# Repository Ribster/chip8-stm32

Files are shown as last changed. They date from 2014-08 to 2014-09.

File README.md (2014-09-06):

CHIP 8 emulator
==========

STM32 based emulator with chip8 virtual machine.

Dirs
==========
tools/	dir with conwerter of image in propertly format
mcu/	program writen to mcu (Eclipse progect)
pcb/	schematics and pcb ready to laser printer production (Eagle)

How to repeat
==========

1. Product pcb
2. SMT components
3. Compile or use prebuild hex/elf files to write in mcu
4. Enjoy

TODO
==========
1. Transfer to new random generator
2. Add button patterns to game (now button worked propertly only in tetris)
3. Add to disign Beeper 
4. Redisign schematics
5. Create case for console

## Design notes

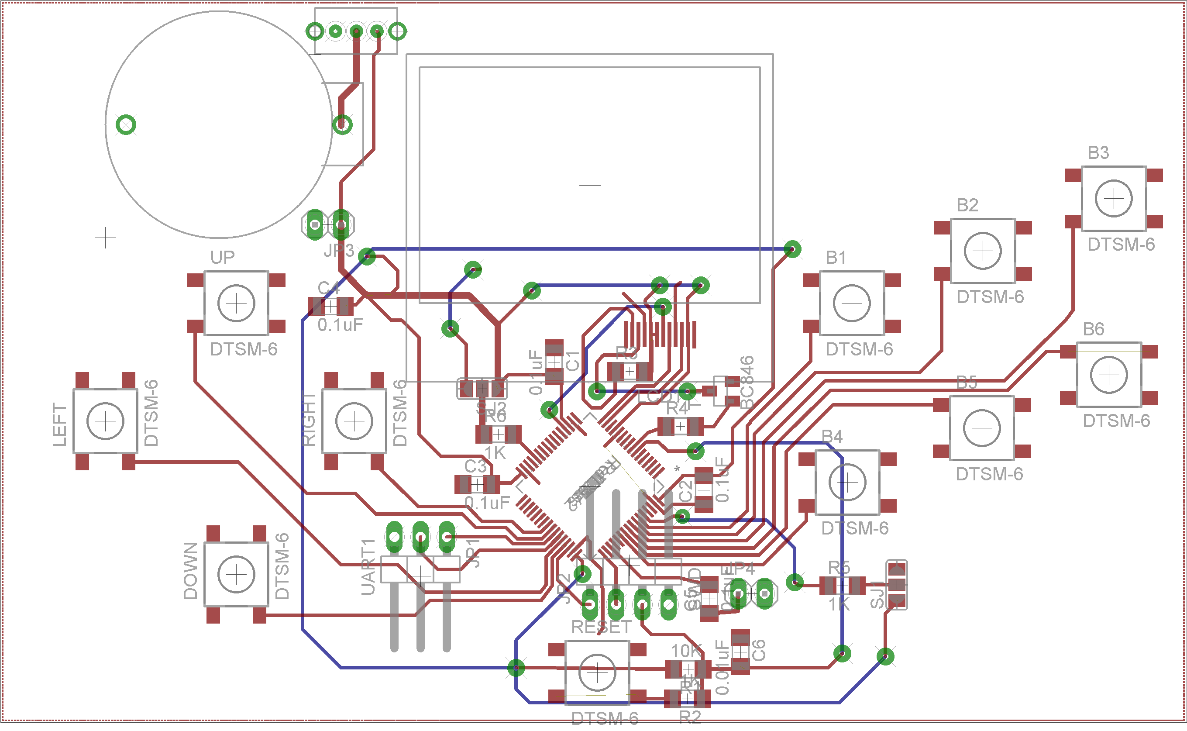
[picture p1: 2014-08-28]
pcb/render/main_board_pcb_elements+2layer.png

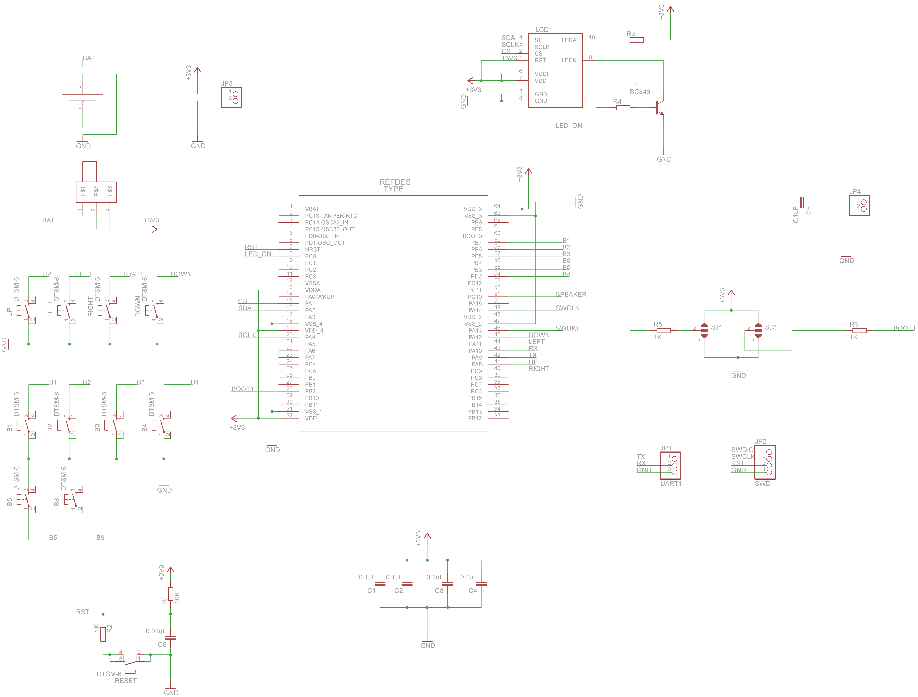
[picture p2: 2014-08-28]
pcb/render/main_board.png

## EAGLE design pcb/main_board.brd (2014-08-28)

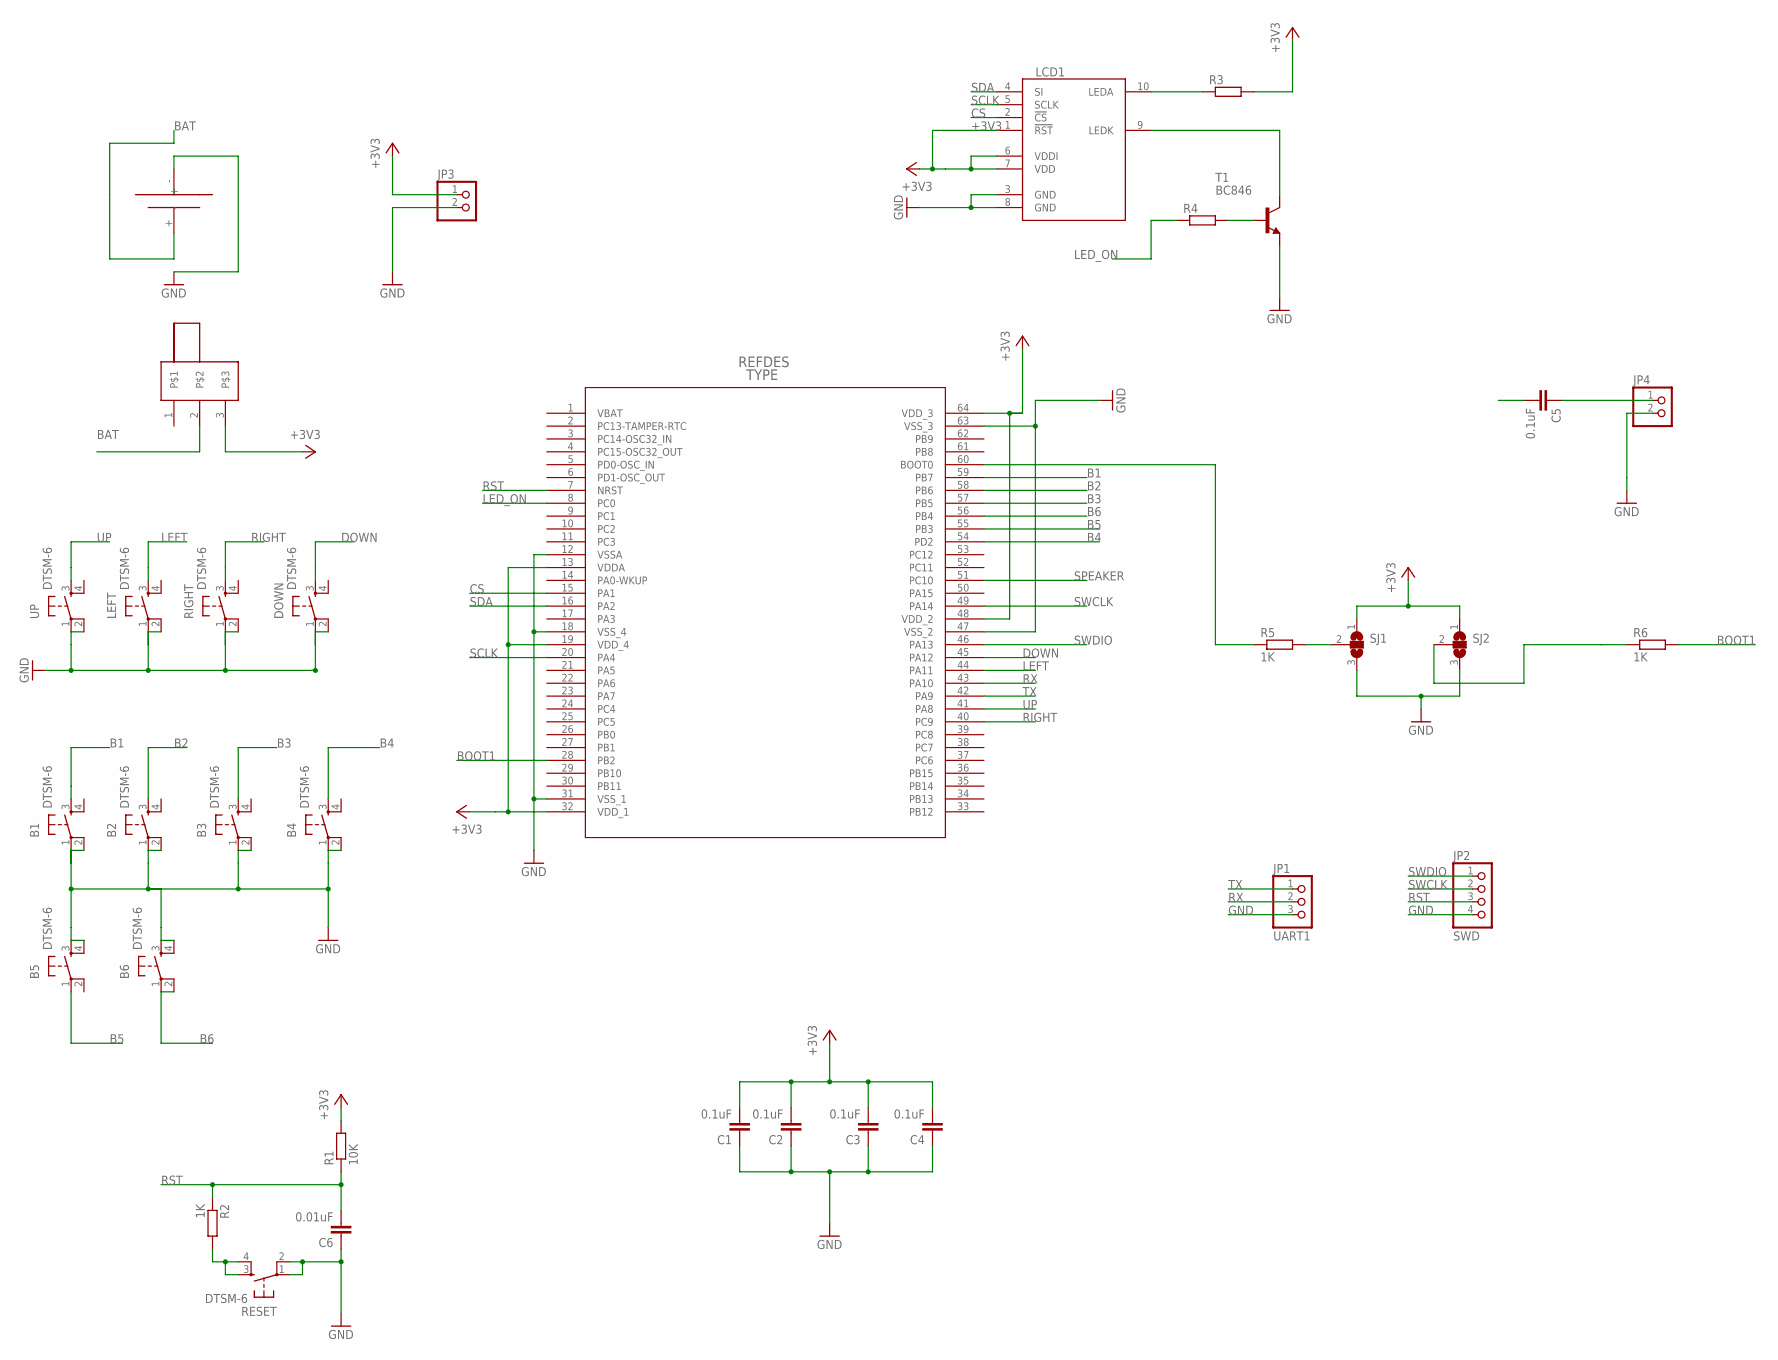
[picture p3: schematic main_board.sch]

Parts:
B1, B2, B3, B4, B5, B6: DTSM-6
C1, C2, C3, C4, C5: 0.1uF; C1206
C6: 0.01uF; C1206
DOWN: DTSM-6
JP1: UART1; 1X03/90
JP2: SWD; 1X04/90
JP3, JP4: PINHD-1X2; 1X02
LCD1: LCD1202; NOKIA1202LCD
LEFT: DTSM-6
R1: 10K; R1206
R2, R5, R6: 1K; R1206
R3, R4: R-EU_R1206; R1206
RESET: DTSM-6
RIGHT: DTSM-6
SJ1, SJ2: SJ2W; SJ_2
T1: BC846; SOT23
U$1: STM32F100RBT6B; LQFP-64
U$2: BAT33; 3V3BATPACK
U$3: SWITCH3
UP: DTSM-6

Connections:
+3V3: C1.2, C2.2, C3.2, C4.2, JP3.1, LCD1.1 (!RST), LCD1.6 (VDDI), LCD1.7 (VDD), R1.2, R3.2, SJ1.1, SJ2.1, U$1.13 (VDDA), U$1.19 (VDD_4), U$1.32 (VDD_1), U$1.48 (VDD_2), U$1.64 (VDD_3), U$3.3
B1: B1.3, U$1.59 (PB7)
B2: B2.3, U$1.58 (PB6)
B3: B3.3, U$1.57 (PB5)
B4: B4.3, U$1.54 (PD2)
B5: B5.1, U$1.55 (PB3)
B6: B6.1, B6.2, U$1.56 (PB4)
BAT: U$2.+, U$3.2
BOOT1: R6.2, U$1.28 (PB2)
CS: LCD1.2 (!CS), U$1.15 (PA1)
DOWN: DOWN.3, U$1.45 (PA12)
GND: B1.1, B1.2, B2.1, B2.2, B3.1, B3.2, B4.1, B4.2, B5.3, B5.4, B6.3, B6.4, C1.1, C2.1, C3.1, C4.1, C6.1, DOWN.1, DOWN.2, JP1.3, JP2.4, JP3.2, JP4.2, LCD1.3 (GND), LCD1.8 (GND), LEFT.1, LEFT.2, RESET.1, RESET.2, RIGHT.1, RIGHT.2, SJ1.3, SJ2.3, T1.2 (E), U$1.12 (VSSA), U$1.18 (VSS_4), U$1.31 (VSS_1), U$1.47 (VSS_2), U$1.63 (VSS_3), U$2.-, UP.1, UP.2
LED_ON: R4.1, U$1.8 (PC0)
LEFT: LEFT.3, U$1.44 (PA11)
unnamed: LCD1.9 (LEDK), T1.3 (C)
unnamed: R4.2, T1.1 (B)
unnamed: R2.2, RESET.3, RESET.4
unnamed: LCD1.10 (LEDA), R3.1
unnamed: R5.1, U$1.60 (BOOT0)
unnamed: R5.2, SJ1.2
unnamed: C5.1, JP4.1
unnamed: R6.1, SJ2.2
RIGHT: RIGHT.3, U$1.40 (PC9)
RST: C6.2, JP2.3, R1.1, R2.1, U$1.7 (NRST)
RX: JP1.2, U$1.43 (PA10)
SCLK: LCD1.5 (SCLK), U$1.20 (PA4)
SDA: LCD1.4 (SI), U$1.16 (PA2)
SPEAKER: C5.2, U$1.51 (PC10)
SWCLK: JP2.2, U$1.49 (PA14)
SWDIO: JP2.1, U$1.46 (PA13)
TX: JP1.1, U$1.42 (PA9)
UP: U$1.41 (PA8), UP.3

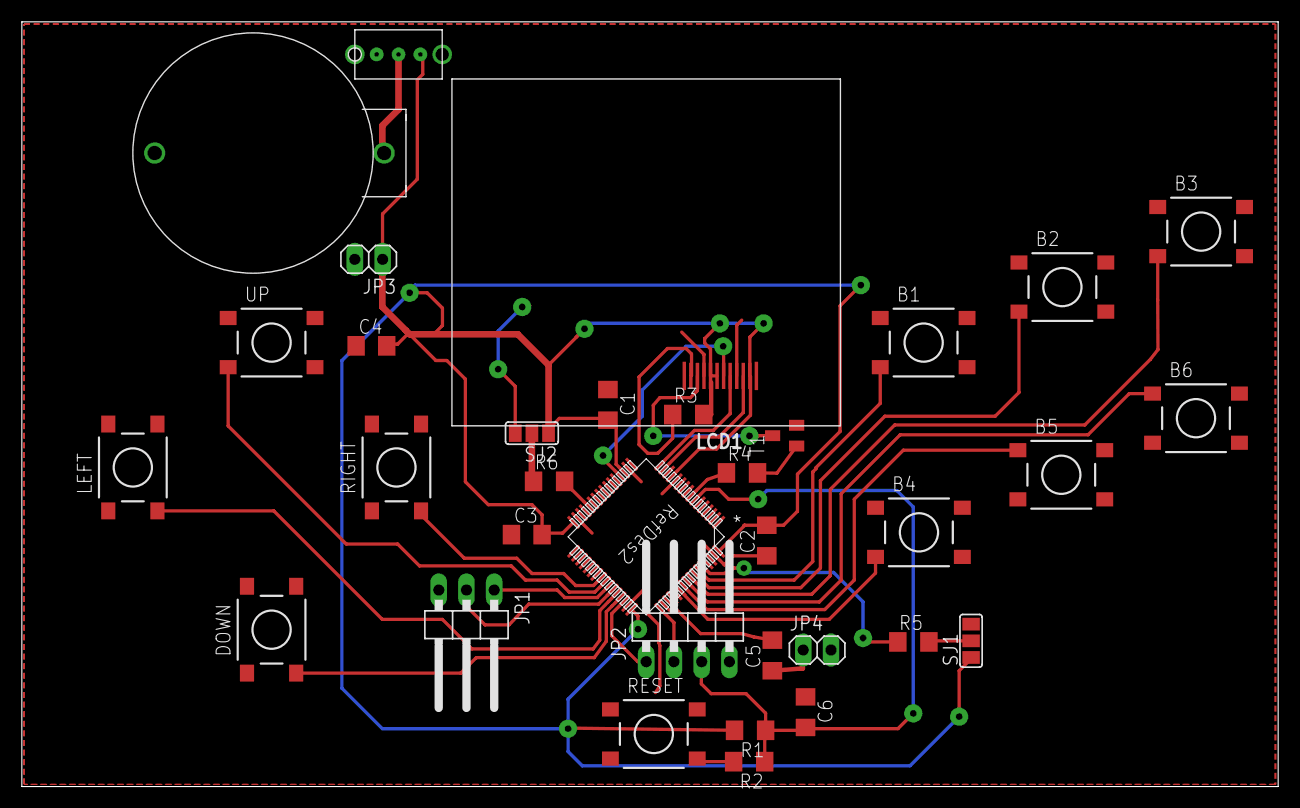
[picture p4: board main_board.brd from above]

Board: 2 copper layers, 115.0 x 70.0 mm, 34 parts (0 on the bottom side), 32 nets.

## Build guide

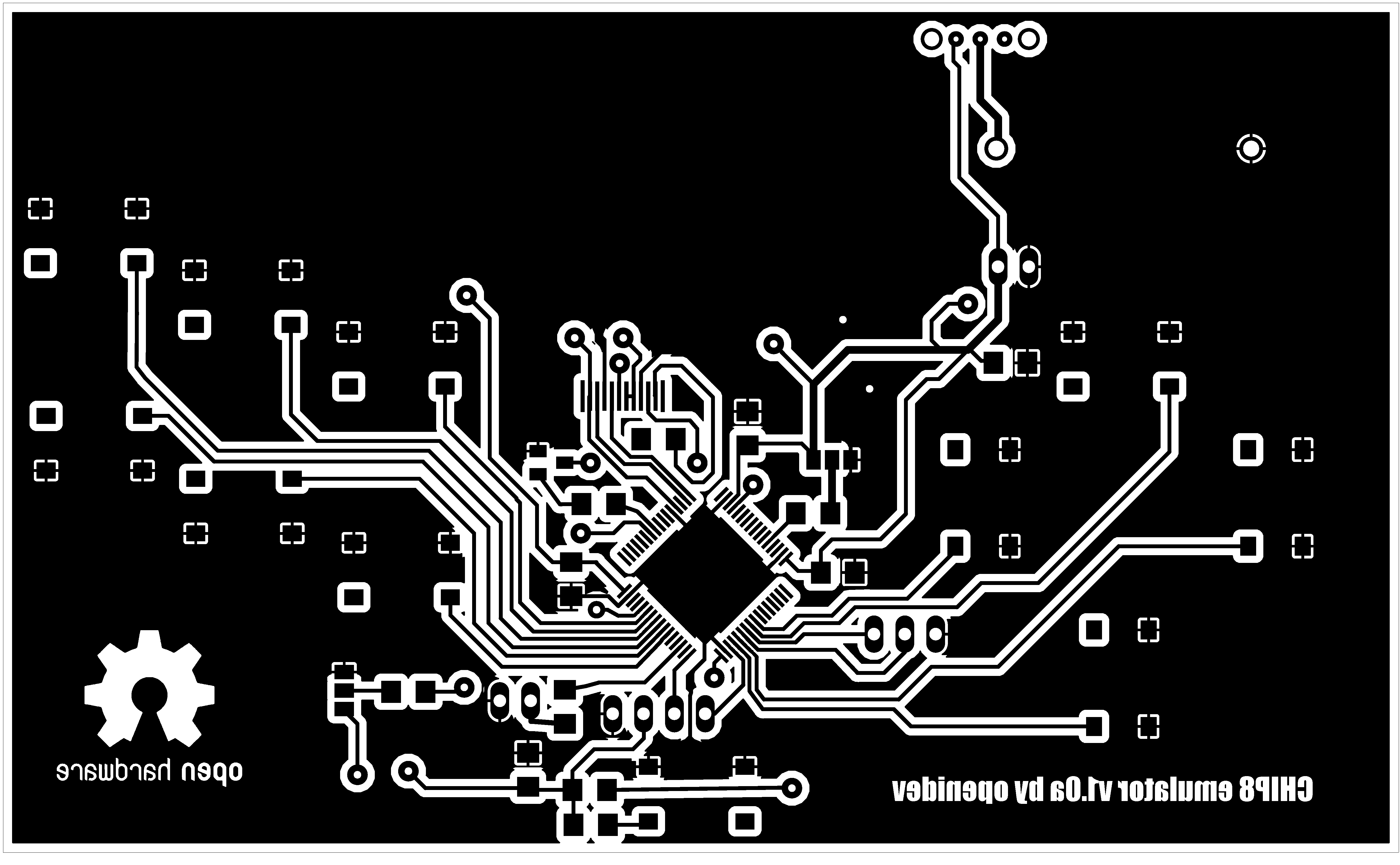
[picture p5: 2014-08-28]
pcb/render/main_board_Laser_Printer_ready_mirored.png

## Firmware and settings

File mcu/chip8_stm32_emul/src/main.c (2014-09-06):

/*
 * main.c
 *
 *  Created on: 25.08.2014
 *      Author: sasha
 */

#include "main.h"

GPIO_InitTypeDef GPIO_InitStructure;
USART_InitTypeDef USART_InitStructure;
USART_ClockInitTypeDef USART_ClockInitStruct;
EXTI_InitTypeDef EXTI_InitStructure;
NVIC_InitTypeDef NVIC_InitStructure;

volatile uint32_t timer;
volatile unsigned int SysTickDelay;

char test[] = "test";
char *disp_string;
char update_lcd;


//Main menu
char select_b;
uint8_t press, current, quit;
volatile uint8_t btn_old_state[10];
volatile uint8_t btn_state[10];


void EnableExti(uint32_t line)
{
	EXTI_InitStructure.EXTI_Line = line;
	EXTI_InitStructure.EXTI_Mode = EXTI_Mode_Interrupt;
	EXTI_InitStructure.EXTI_Trigger = EXTI_Trigger_Falling;
	EXTI_InitStructure.EXTI_LineCmd = ENABLE;
	EXTI_Init(&EXTI_InitStructure);


	/*NVIC_InitStructure.NVIC_IRQChannel = irq;
	NVIC_InitStructure.NVIC_IRQChannelPreemptionPriority = 0x01;
	NVIC_InitStructure.NVIC_IRQChannelSubPriority = 0x01;
	NVIC_InitStructure.NVIC_IRQChannelCmd = ENABLE;
	NVIC_Init(&NVIC_InitStructure);*/

}

void initButtons(void)
{
	GPIO_PinRemapConfig(GPIO_Remap_SWJ_NoJTRST, ENABLE);
	GPIO_PinRemapConfig(GPIO_Remap_SWJ_JTAGDisable, ENABLE);


	GPIO_InitStructure.GPIO_Mode = GPIO_Mode_IPU;
	GPIO_InitStructure.GPIO_Pin = GPIO_Pin_3 | GPIO_Pin_4 | GPIO_Pin_5 | GPIO_Pin_6 | GPIO_Pin_7;
	GPIO_InitStructure.GPIO_Speed = GPIO_Speed_2MHz;
	GPIO_Init(GPIOB, &GPIO_InitStructure);

	GPIO_InitStructure.GPIO_Pin = GPIO_Pin_2;
	GPIO_Init(GPIOD, &GPIO_InitStructure);

	GPIO_InitStructure.GPIO_Pin = GPIO_Pin_8 | GPIO_Pin_11 | GPIO_Pin_12;
	GPIO_Init(GPIOA, &GPIO_InitStructure);

	GPIO_InitStructure.GPIO_Pin = GPIO_Pin_9;
	GPIO_Init(GPIOC, &GPIO_InitStructure);

	//Button b1,b2,b3,b5,b6
	GPIO_EXTILineConfig(GPIO_PortSourceGPIOB, GPIO_PinSource3);
	GPIO_EXTILineConfig(GPIO_PortSourceGPIOB, GPIO_PinSource4);
	GPIO_EXTILineConfig(GPIO_PortSourceGPIOB, GPIO_PinSource5);
	GPIO_EXTILineConfig(GPIO_PortSourceGPIOB, GPIO_PinSource6);
	GPIO_EXTILineConfig(GPIO_PortSourceGPIOB, GPIO_PinSource7);
	//Button b4
	GPIO_EXTILineConfig(GPIO_PortSourceGPIOD, GPIO_PinSource2);

	//Button down, left, up
	GPIO_EXTILineConfig(GPIO_PortSourceGPIOA, GPIO_PinSource8);
	GPIO_EXTILineConfig(GPIO_PortSourceGPIOA, GPIO_PinSource11);
	GPIO_EXTILineConfig(GPIO_PortSourceGPIOA, GPIO_PinSource12);
	//button right
	GPIO_EXTILineConfig(GPIO_PortSourceGPIOC, GPIO_PinSource9);

	EnableExti(EXTI_Line2);
	EnableExti(EXTI_Line3);
	EnableExti(EXTI_Line4);
	EnableExti(EXTI_Line5);
	EnableExti(EXTI_Line6);
	EnableExti(EXTI_Line7);
	EnableExti(EXTI_Line8);
	EnableExti(EXTI_Line9);
	EnableExti(EXTI_Line11);
	EnableExti(EXTI_Line12);

	NVIC_EnableIRQ(EXTI2_IRQn);
	NVIC_EnableIRQ(EXTI3_IRQn);
	NVIC_EnableIRQ(EXTI4_IRQn);
	NVIC_EnableIRQ(EXTI9_5_IRQn);
	NVIC_EnableIRQ(EXTI15_10_IRQn);

	//EnableIRQ(EXTI2_IRQn, EXTI_Line2);
}

void main(void)
{
	  SysTick_Config(SystemCoreClock /1000);

	  /* Включаем тактирование порта C */
	  RCC_APB2PeriphClockCmd(RCC_APB2Periph_GPIOA | RCC_APB2Periph_GPIOC |
			  	  	  	  	 RCC_APB2Periph_GPIOB | RCC_APB2Periph_GPIOB |
			  	  	  	  	 RCC_APB2Periph_GPIOD | RCC_APB2Periph_AFIO, ENABLE);

	  RCC_APB1PeriphClockCmd(RCC_APB1Periph_USART2 , ENABLE);


	  initButtons();


	  /* Init usart spi */
	  GPIO_InitStructure.GPIO_Pin = GPIO_Pin_2 | GPIO_Pin_4;
	  GPIO_InitStructure.GPIO_Mode = GPIO_Mode_Out_PP;
	  GPIO_InitStructure.GPIO_Speed = GPIO_Speed_10MHz;

	  GPIO_Init( GPIOA , &GPIO_InitStructure);

	  /*USART_Cmd(USART2, ENABLE);
	  USART_InitStructure.USART_BaudRate = 9600;
	  USART_InitStructure.USART_WordLength = USART_WordLength_9b;
	  USART_InitStructure.USART_StopBits = USART_StopBits_1;
	  USART_InitStructure.USART_Parity = USART_Parity_No ;
	  USART_InitStructure.USART_Mode = USART_Mode_Tx;
	  USART_InitStructure.USART_HardwareFlowControl = USART_HardwareFlowControl_None;*/
	  /* Configure USART2 */
	  //USART_Init(USART2, &USART_InitStructure);

	  //USART1->BRR = 0x0010;

	  /* Configure USART2 clock*/
	  /*USART_ClockStructInit(&USART_ClockInitStruct);
	  USART_ClockInitStruct.USART_Clock = USART_Clock_Enable;
	  USART_ClockInitStruct.USART_LastBit = USART_LastBit_Enable;
	  USART_ClockInit(USART2, &USART_ClockInitStruct);*/


	  /* Init lcd led control pin */
	  GPIO_InitStructure.GPIO_Mode = GPIO_Mode_Out_PP;
	  GPIO_InitStructure.GPIO_Pin = GPIO_Pin_0;
	  GPIO_InitStructure.GPIO_Speed = GPIO_Speed_2MHz;
	  GPIO_Init(GPIOC, &GPIO_InitStructure);


	  /* Init lcd controll CS signal */
	  GPIO_InitStructure.GPIO_Mode = GPIO_Mode_Out_PP;
	  GPIO_InitStructure.GPIO_Pin = GPIO_Pin_1;
	  GPIO_InitStructure.GPIO_Speed = GPIO_Speed_2MHz;
	  GPIO_Init(GPIOA, &GPIO_InitStructure);


	  /* ON LED backlight */
	  GPIO_SetBits(GPIOC, GPIO_Pin_0);


	  uint8_t i;
	  for (i=0;i<10;i++) {
			btn_old_state[i] = btn_state[i] = 0;
	  }

	  press=1;
	  quit=0;
	  current=1;
	  select_b=0;


	  disp_string = test;
	  update_lcd = 1;

	  /*-----------------*/
	  	lcd_init();
	  	//lcd_segment_direction(1);
	  	lcd_column_direction(1);
	  	//lcd_flags.inverse_char = -1;
	  	lcd_image(0, 0, 8, 96, CHIP8);
	  	delay_ms(1000);
	  	//do __NOP(); while (1); // зависаем
	  	lcd_clr();
	    lcd_str_center(lcdRows()-1, "chip8 emulator");

	    //int cnt = 0;
	    //int i = 0;
	    //uint8_t okeys = 0xFF;

	for(;;) {
	    while(1)
	    {
	        //int n = cnt;
	        //uint8_t keys = (~GPIOB->IDR) & 0x1F;
	        //uint8_t keys = GPIOB->IDR & 0b11111111;


			if(!press) break;

			if(current!=select_b){
				lcd_clr();
				lcd_image(lcdRows()/2, lcdWidth()-15, 1, 4, menu_cursor);
				if(select_b!=0) {
					lcd_str(lcdRows()/2-1, 20, menu_table[select_b-1]);
				}
				lcd_str(lcdRows()/2, 20, menu_table[select_b]);
				if(select_b<MENU_LEN) {
					lcd_str(lcdRows()/2+1, 20, menu_table[select_b+1]);
				}

				current=select_b;

				//lcd_str(0, 0, disp_string);
			}

	    	if(update_lcd)
	    	{
	        //lcd_str(0, 0, disp_string);
	        update_lcd = 0;
	    	}

	    	//delay_ms(100);
			update_controll_button();

	  	    //disp_string = test;
	  	    //update_lcd = 1;

	        /*for(i=6; i>=0; i--)
	        {
	            //ledOn();
	            lcd_big_char(1, 2+i*13, (n % 10)+'0');
	            //ledOff();
	            n /= 10;

	            if(keys != okeys)
	            {
	                if(keys & (1<<i))
	                    lcd_big_char(4, 2+i*13, i+'0');
	                else
	                    lcd_big_char(4, 2+i*13, '0'+14);
	            }
	        }*/
	        //okeys = keys;
	        // lcd_start_line(cnt>>8);

	        //cnt++;
	        //if(cnt>9999999) cnt = 0;
	    }

		init8();
		loadApplication(prog_table[current],prog_size[current]);
		//loadApplication(MAZE,38);
		uint8_t x,y;
		while(1) {
			emulateCycle();
			delay_ms(5);
			if(drawFlag) {
				//lcd_clr();
				for(y = 18; y < 50; ++y)
				{
					for(x = 20; x < 84; ++x)
					{
						if(gfx[((y-18)*64) + (x-20)] == 0)
							lcd_pixel(100-x,y,PIXEL_OFF);
						else
							lcd_pixel(100-x,y,PIXEL_ON);
					}
				}
				/*for(y = 0; y < 32; y++)
				{
					for(x = 0; x < 64; x++)
					{
						if(gfx[(y*64) + x] == 0)
							lcd_pixel(x,y,PIXEL_OFF);
						else
							lcd_pixel(x,y,PIXEL_ON);
					}
				}*/
				drawFlag = false;
				lcd_update();
				//lcd_str(0, 0, disp_string);
			}
			update_game_button();

			if(quit)
			{
				press=1;
				quit = 0;
				current=1;
				select_b=0;
				break;
			}

		}

	}
/*-----------------*/
	  do __NOP(); while (1); // зависаем
}


void update_controll_button()
{
	if (btn_state[UP] && GPIO_ReadInputDataBit(GPIOA, GPIO_Pin_8))
	{
		select_b--;
		//delay_ms(200);
		btn_state[UP] = 0;
	}
	if (btn_state[DOWN] && GPIO_ReadInputDataBit(GPIOA, GPIO_Pin_12))
	{
		select_b++;
		//delay_ms(200);
		btn_state[DOWN] = 0;
	}
	if (btn_state[B4]&& GPIO_ReadInputDataBit(GPIOD, GPIO_Pin_2))
	{
		press=0;
		//delay_ms(200);
		btn_state[B4] = 0;
	}

	if (btn_state[B5]&& GPIO_ReadInputDataBit(GPIOB, GPIO_Pin_3))
	{
		if(GPIO_ReadInputDataBit(GPIOC, GPIO_Pin_0))
			GPIO_ResetBits(GPIOC, GPIO_Pin_0);
		else
			GPIO_SetBits(GPIOC, GPIO_Pin_0);
		//delay_ms(200);
		btn_state[B5] = 0;
	}
	//egg
	if (btn_state[B6]&& GPIO_ReadInputDataBit(GPIOB, GPIO_Pin_4))
	{
		lcd_image(0, 0, 8, 96, BAW);
		btn_state[B6] = 0;
	}

	if(select_b == 255) select_b=MENU_LEN;
	if(select_b > MENU_LEN) select_b=0;

}

void update_game_button() {
	byte i[5];
	i[0] = GPIO_ReadInputDataBit(GPIOA, GPIO_Pin_8);
	i[1] = GPIO_ReadInputDataBit(GPIOA, GPIO_Pin_12);
	i[3] = GPIO_ReadInputDataBit(GPIOC, GPIO_Pin_11);
	i[2] = GPIO_ReadInputDataBit(GPIOC, GPIO_Pin_9);
	i[4] = GPIO_ReadInputDataBit(GPIOD, GPIO_Pin_2);

	if (btn_state[UP] && i[0])
	{
		key[0x4] =1;
		btn_state[UP] = 0;
	}
	else if (!btn_state[UP])
		key[0x4] =0;
	if (btn_state[DOWN] && i[1])
	{
		key[0xD] =1;
		btn_state[DOWN] = 0;
	}
	else if (!btn_state[DOWN])
		key[0xD] =0;
	if (btn_state[RIGHT] && i[2])
	{
		key[0x6] =1;
		btn_state[RIGHT] = 0;
	}
	else if (!btn_state[RIGHT])
		key[0x6] =0;
	if (btn_state[LEFT] && i[3])
	{
		key[0x5] =1;
		btn_state[LEFT] = 0;
	}
	else if (!btn_state[btn_state[LEFT]])
		key[0x5] =0;

	//quit
	if (btn_state[B4] && i[4])
	{
		quit =1;
		btn_state[B4] = 0;
	}
	else if (!btn_state[btn_state[B4]])
		quit =0;
}

void SysTick_Worker(void) {
	timer++;
	if (SysTickDelay != 0) {
		SysTickDelay--;
	}

}

void delay_ms(unsigned int nCount) {
	SysTickDelay = nCount;
	while (SysTickDelay != 0) {};
}
